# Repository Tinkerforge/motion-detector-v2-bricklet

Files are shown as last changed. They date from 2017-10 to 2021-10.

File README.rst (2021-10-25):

Motion Detector Bricklet 2.0
============================

This repository contains the firmware source code and the hardware design
files. The documentation generator configs can be found at
https://github.com/Tinkerforge/generators

Repository Content
------------------

software/:
 * examples/: Examples for all supported languages
 * build/: Compiled files
 * src/: Source code of firmware
 * Makefile: Makefile to build project

hardware/:
 * Contains KiCad project files and additionally schematics as PDF

datasheets/:
 * Contains datasheets for sensors and complex ICs that are used

Hardware
--------

The hardware is designed with the open source EDA Suite KiCad
(http://www.kicad.org). Before you are able to open the files,
you have to install the Tinkerforge kicad-libraries
(https://github.com/Tinkerforge/kicad-libraries). You can either clone
them directly in hardware/ or clone them in a separate folder and
symlink them into hardware/
(ln -s kicad_path/kicad-libraries project_path/hardware). After that you
can open the .pro file in hardware/ with KiCad and from there view and
modify the schematics and the PCB layout.

Software
--------

If you want to do your own Brick/Bricklet firmware development we highly
recommend that you use our build environment setup script and read the
tutorial (https://www.tinkerforge.com/en/doc/Tutorials/Tutorial_Build_Environment/Tutorial.html).

To compile the C code we recommend you to install the newest GNU Arm Embedded
Toolchain (https://launchpad.net/gcc-arm-embedded/+download).
You also need to install bricklib2 (https://github.com/Tinkerforge/bricklib2).

You can either clone it directly in software/src/ or clone it in a
separate folder and symlink it into software/src/
(ln -s bricklib_path/bricklib2 project_path/software/src/). Finally make sure to
have CMake installed (http://www.cmake.org/cmake/resources/software.html).

After that you can build the firmware by invoking make in software/.
The firmware (.zbin) can then be found in software/build/ and uploaded
with brickv (click button "Flashing" on start screen).

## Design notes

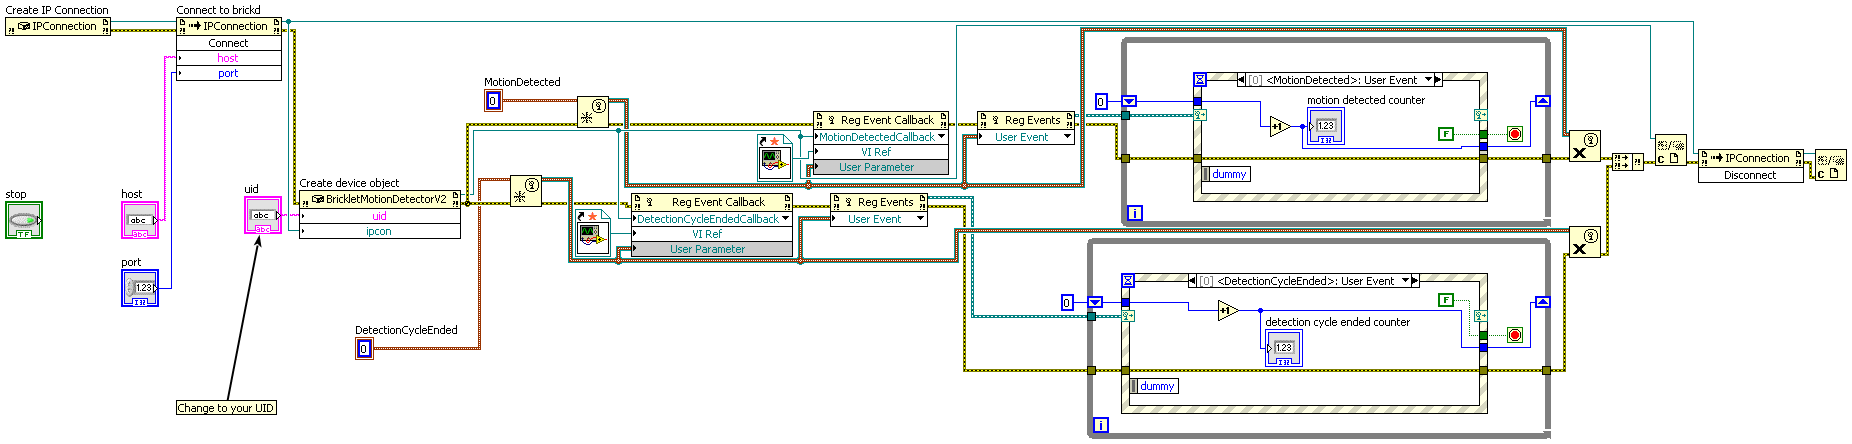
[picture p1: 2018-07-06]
software/examples/labview/Example Callback.vi.png

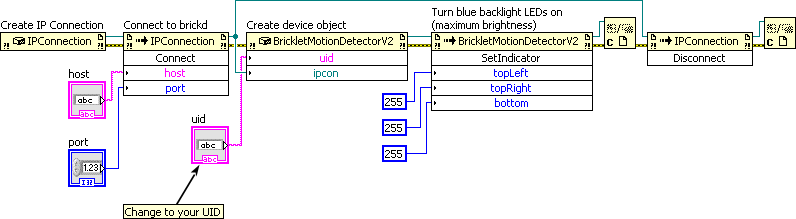
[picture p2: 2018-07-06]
software/examples/labview/Example Indicator.vi.png

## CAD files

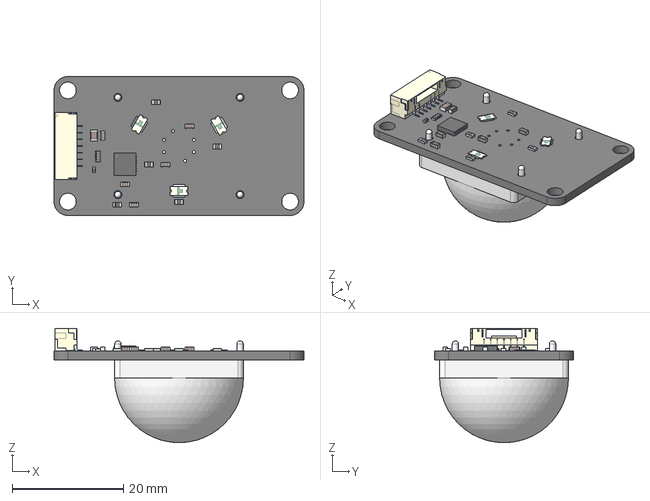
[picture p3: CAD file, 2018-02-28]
hardware/motion-detector-v2.step
45.0 x 25.0 x 20.6 mm

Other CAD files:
hardware/motion-detector-v2.FCStd

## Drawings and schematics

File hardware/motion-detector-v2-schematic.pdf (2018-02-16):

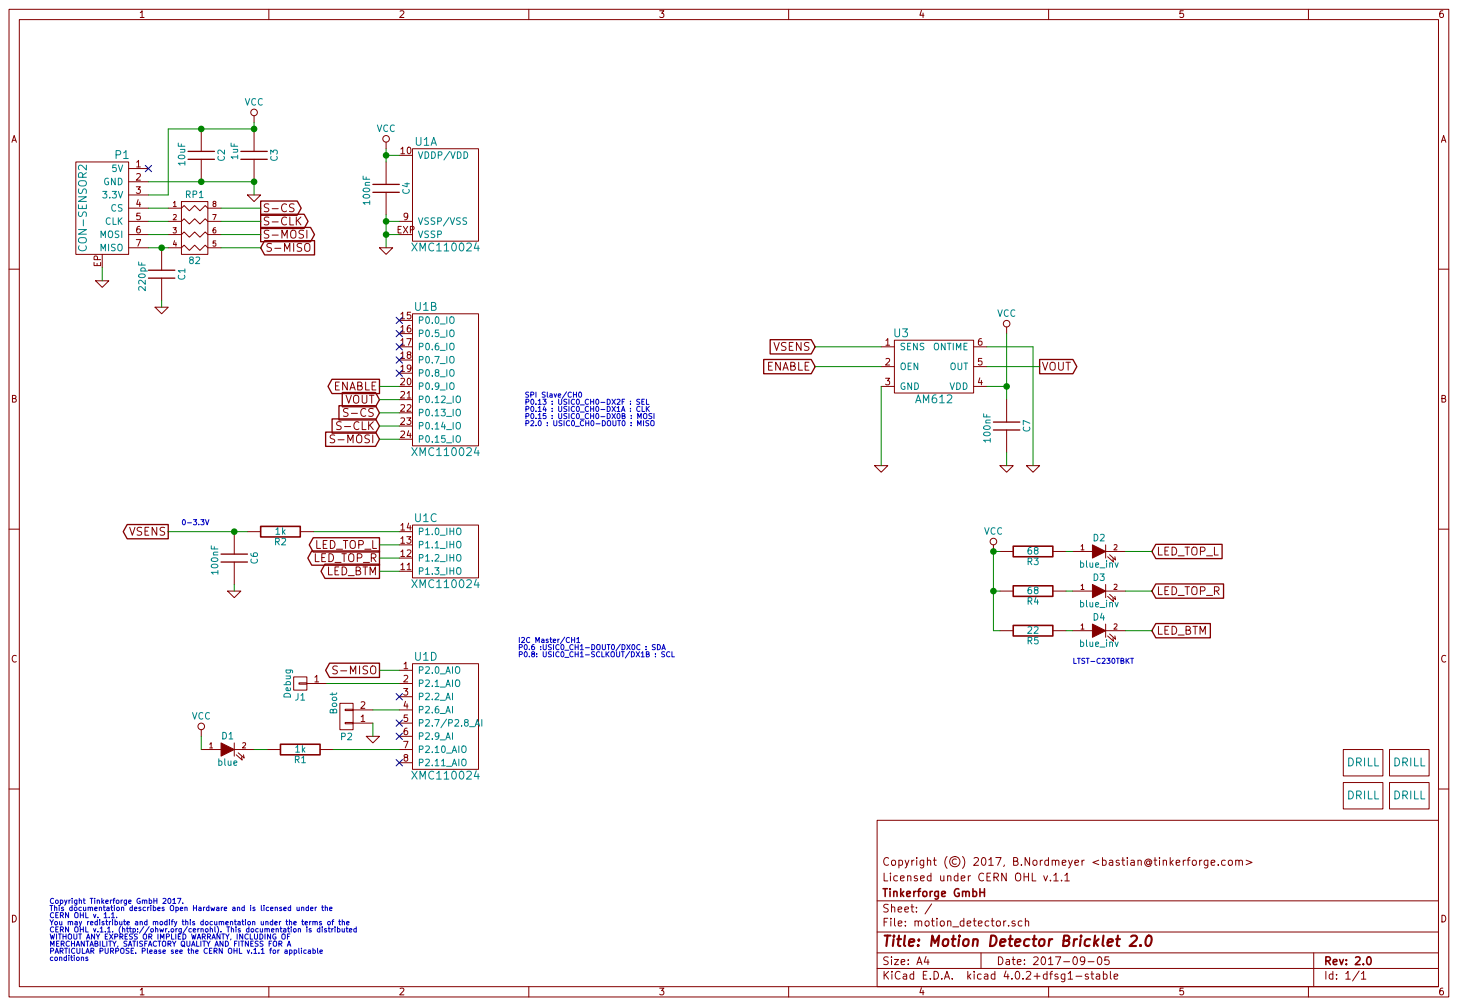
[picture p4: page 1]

SPI Slave/CH0 P0.13 : USIC0_CH0-DX2F : SEL P0.14 : USIC0_CH0-DX1A : CLK

Licensed under CERN OHL v.1.1 Copyright (©) 2017, B.Nordmeyer <bastian@tinkerforge.com>

File: motion_detector.sch Sheet: / Tinkerforge GmbH

Copyright Tinkerforge GmbH 2017. This documentation describes Open Hardware and is licensed under the CERN OHL v. 1.1. You may redistribute and modify this documentation under the terms of the CERN OHL v.1.1. (http://ohwr.org/cernohl). This documentation is distributed WITHOUT ANY EXPRESS OR IMPLIED WARRANTY, INCLUDING OF MERCHANTABILITY, SATISFACTORY QUALITY AND FITNESS FOR A

Id: 1/1 Title: Motion Detector Bricklet 2.0

PARTICULAR PURPOSE. Please see the CERN OHL v.1.1 for applicable

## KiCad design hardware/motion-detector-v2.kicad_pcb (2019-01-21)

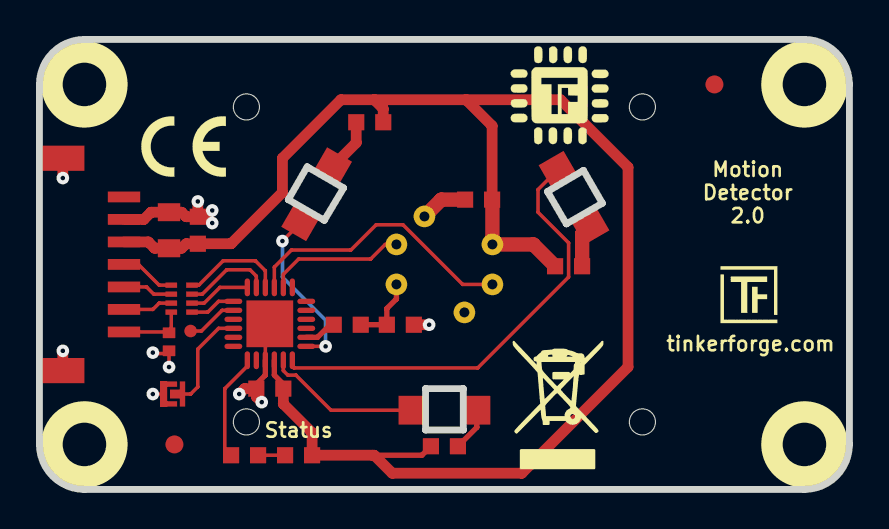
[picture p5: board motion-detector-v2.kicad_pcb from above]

Board: 2 copper layers, 45.0 x 25.0 mm, 29 parts (0 on the bottom side), 24 nets.

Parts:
C1: 220pF; C0402F
C2: 10uF; C0805
C3: 1uF; C0603F
C4, C6, C7: 100nF; C0603F
D1: blue; D0603F
D2, D3, D4: blue_inv; D1206_INV
Fiducial_Mark: VAL**; Fiducial_Mark
Fiducial_Mark#2: VAL**; Fiducial_Mark
J1: Debug; DEBUG_PAD
P1: CON-SENSOR2
P2: Boot; SolderJumper
R1, R2: 1k; R0603F
R3, R4: 68; R0603F
R5: 22; R0603F
RP1: 82; 4X0402
U1: XMC110024; QFN24-4x4mm-0.5mm
U3: AM612
U4, U5, U6, U7: DRILL; DRILL_NP
VAL: WEEE_7mm
VAL#2: CE_5mm

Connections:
ENABLE: U1.20, U3.2
GND: C1.1, C2.1, C3.1, C4.1, C6.1, C7.1, P1.2, P1.EP, P2.1, U1.9, U1.EXP, U3.3, U3.6
LED_BTM: D4.2, U1.11
LED_TOP_L: D2.2, U1.13
LED_TOP_R: D3.2, U1.12
unnamed: C1.2, P1.7, RP1.4
unnamed: D1.2, R1.2
unnamed: D2.1, R3.1
unnamed: D3.1, R4.1
unnamed: D4.1, R5.1
unnamed: J1.1, U1.2
unnamed: P1.4, RP1.1
unnamed: P1.5, RP1.2
unnamed: P1.6, RP1.3
unnamed: P2.2, U1.4
unnamed: R1.1, U1.7
unnamed: R2.1, U1.14
S-CLK: RP1.7, U1.23
S-CS: RP1.8, U1.22
S-MISO: RP1.5, U1.1
S-MOSI: RP1.6, U1.24
VCC: C2.2, C3.2, C4.2, C7.2, D1.1, P1.3, R3.2, R4.2, R5.2, U1.10, U3.4
VOUT: U1.21, U3.5
VSENS: C6.2, R2.2, U3.1

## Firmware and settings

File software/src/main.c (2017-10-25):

/* motion-detector-v2-bricklet
 * Copyright (C) 2017 Olaf Lüke <olaf@tinkerforge.com>
 *
 * main.c: Initialization for Motion Detector V2 Bricklet
 *
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
 * You should have received a copy of the GNU Lesser General Public
 * License along with this library; if not, write to the
 * Free Software Foundation, Inc., 59 Temple Place - Suite 330,
 * Boston, MA 02111-1307, USA.
 */

#include <stdio.h>
#include <stdbool.h>

#include "configs/config.h"

#include "bricklib2/bootloader/bootloader.h"
#include "bricklib2/hal/system_timer/system_timer.h"
#include "bricklib2/logging/logging.h"
#include "communication.h"
#include "am612.h"

int main(void) {
	logging_init();
	logd("Start Motion Detector V2 Bricklet\n\r");

	communication_init();
	am612_init();

	while(true) {
		bootloader_tick();
		communication_tick();
		am612_tick();
	}
}

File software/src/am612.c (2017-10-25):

/* motion-detector-v2-bricklet
 * Copyright (C) 2017 Olaf Lüke <olaf@tinkerforge.com>
 *
 * am612.c: AM612 PIR Sensor driver
 *
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
 * You should have received a copy of the GNU Lesser General Public
 * License along with this library; if not, write to the
 * Free Software Foundation, Inc., 59 Temple Place - Suite 330,
 * Boston, MA 02111-1307, USA.
 */

#include "am612.h"

#include "configs/config_am612.h"

#include "bricklib2/logging/logging.h"
#include "bricklib2/hal/ccu4_pwm/ccu4_pwm.h"

#include "xmc_gpio.h"

AM612 am612;

void am612_init(void) {
	const XMC_GPIO_CONFIG_t enable_pin_config = {
		.mode         = XMC_GPIO_MODE_OUTPUT_PUSH_PULL,
		.output_level = XMC_GPIO_OUTPUT_LEVEL_HIGH,
	};
	XMC_GPIO_Init(AM612_ENABLE_PIN, &enable_pin_config);

	const XMC_GPIO_CONFIG_t vout_pin_config = {
		.mode             = XMC_GPIO_MODE_INPUT_TRISTATE,
		.input_hysteresis = XMC_GPIO_INPUT_HYSTERESIS_LARGE,
	};
	XMC_GPIO_Init(AM612_VOUT_PIN, &vout_pin_config);

	ccu4_pwm_init(AM612_SENSITIVITY_PIN, AM612_SENSITIVITY_CCU4_SLICE, 400);

	ccu4_pwm_init(LED_TOP_LEFT_PIN,  LED_TOP_LEFT_CCU4_SLICE,  LED_PERIOD_VALUE);
	ccu4_pwm_init(LED_TOP_RIGHT_PIN, LED_TOP_RIGHT_CCU4_SLICE, LED_PERIOD_VALUE);
	ccu4_pwm_init(LED_BOTTOM_PIN,    LED_BOTTOM_CCU4_SLICE,    LED_PERIOD_VALUE);

	memset(&am612, 0, sizeof(AM612));
	am612.sensitivity = 50;
	am612.sensivitity_last = 255;
}

void am612_tick(void) {
	if(am612.sensitivity != am612.sensivitity_last) {
		ccu4_pwm_set_duty_cycle(AM612_SENSITIVITY_CCU4_SLICE, 300 + am612.sensitivity);
		am612.sensivitity_last = am612.sensitivity;
		logd("AM612: New sens %u\n\r", am612.sensitivity);
	}

	if(am612.top_left != am612.top_left_last) {
		ccu4_pwm_set_duty_cycle(LED_TOP_LEFT_CCU4_SLICE, am612.top_left);
		am612.top_left_last = am612.top_left;
		logd("AM612: New top_left %u\n\r", am612.top_left);
	}

	if(am612.top_right != am612.top_right_last) {
		ccu4_pwm_set_duty_cycle(LED_TOP_RIGHT_CCU4_SLICE, am612.top_right);
		am612.top_right_last = am612.top_right;
		logd("AM612: New top_right %u\n\r", am612.top_right);
	}

	if(am612.bottom != am612.bottom_last) {
		ccu4_pwm_set_duty_cycle(LED_BOTTOM_CCU4_SLICE, am612.bottom);
		am612.bottom_last = am612.bottom;
		logd("AM612: New bottom %u\n\r", am612.bottom);
	}

	bool new_vout = XMC_GPIO_GetInput(AM612_VOUT_PIN);
	if(new_vout != am612.vout) {
		if(new_vout) {
			am612.send_motion_detected = true;
		} else {
			am612.send_detection_cycle_ended = true;
		}
		logd("AM612: New vout %u\n\r", new_vout);
		am612.vout = new_vout;
	}

}

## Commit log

2017-09-05 add hardware files of motion detector 2.0
    [motion_detector.kicad_pcb, motion_detector.sch]
2017-09-05 add cutouts for leds
    [motion_detector.kicad_pcb]
2017-09-29 fix ams612 routing, change led positions
    [motion_detector.kicad_pcb, motion_detector.sch]
2017-10-04 Add mcp4018, am612 + led drivers and communication implementation
    [cmake_config_custom.txt]
2017-10-19 version without i2c poti, uses rc circuit
    [motion_detector.kicad_pcb, motion_detector.sch]
2017-10-19 fix status led text
    [motion_detector.kicad_pcb]
2017-10-25 change rgb leds to 3x blue
    [motion_detector.kicad_pcb, motion_detector.sch]
2017-10-25 Use PWM as voltage source, remove mcp4018 i2c poti
2017-10-25 Change naming for all blue LEDs instead of RGB
2017-10-26 specify prozessor type
    [motion_detector.kicad_pcb, motion_detector.sch]
2018-01-15 Remove unused ICs and lenses to avoid confusion
2018-02-15 Fix edge cuts
    [motion_detector.kicad_pcb]
2018-02-15 Add 3d information (final)
    [motion_detector.kicad_pcb]
2018-02-15 Add 3d model (*.step & *.FCStd)
    [motion_detector.FCStd, motion_detector.step]
2018-02-16 Add schematic (PDF)
2018-02-19 add cutout information
    [motion_detector.kicad_pcb]
2018-02-20 Cleanup KiCad libraries config
    Ensure LibDir=kicad-libraries and LibName1=tinkerforge.
    Remove special library.
2018-02-28 Add new 3d model with more detailed components
    [motion_detector.FCStd, motion_detector.kicad_pcb, motion_detector.step]
2018-05-11 Rename files
    [motion-detector-v2.FCStd, motion-detector-v2.kicad_pcb, motion-detector-v2.sch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]
2018-06-18 Change capacitor footprint(s) to C0402F
    [motion-detector-v2.kicad_pcb, motion-detector-v2.sch]
2019-01-21 fix status text, add bottom copper masking for sensor
    [motion-detector-v2.kicad_pcb]
2019-08-22 c: Adapt to bindings changes
    [example_callback.c]
2020-09-02 uc: Add example driver note.
2021-10-25 Update KiCad link
    https://www.kicad.org/blog/2021/10/Avoid-links-to-former-kicad-domain/
2022-04-27 uc: Adapt to bindings changes
    [example_callback.c]
